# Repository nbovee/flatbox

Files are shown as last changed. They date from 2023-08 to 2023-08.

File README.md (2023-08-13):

# Flatbox: Low profile hitbox-layout fightstick

This repository contains 3D-printable models, PCB design files and code needed to make an arcade controller that looks like this:

Assembled Flatbox

There are five major versions of the Flatbox. As this is a fork, the three I do not have modifications planned for have been dropped, find them [here](https://github.com/jfedor2/flatbox). They all use Kailh low profile (choc v1) mechanical keyboard switches. The table below lists their main features. See the README for each version for details on how to make them.

version | [rev4](rev4b-pcb) | [rev5B](rev5b-pcb)
------- | --------------------- | ---------------------
case dimensions | 218x130x10mm | 218x126x10mm
compatibility (using provided firmware) | PC, PS3 | PC, PS3
add-on board | - | [RP2040-Zero](https://www.waveshare.com/rp2040-zero.htm)
onboard chip | RP2040 | - 
port | USB-C | USB-C
SMT assembly required | yes | no
firmware | [RP2040](firmware-rp2040) | [RP2040](firmware-rp2040)

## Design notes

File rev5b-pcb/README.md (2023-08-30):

# Flatbox rev5B

This is rev5B of the Flatbox. In this version an [RP2040-Zero](https://www.waveshare.com/rp2040-zero.htm) board is soldered onto the main PCB.
In this version L3 & R3 have been relocated to allow for usage during play (bindable macro's like MK+HK, burst, taunt, etc). 

To make one you will need:

* [3D printed case parts](../case-manufacturing-files) - Select a top and bottom. Two colors tops are available if you have a capable printer.
* [the Flatbox 5B PCB](manufacturing-files)

* [RP2040-Zero](https://www.waveshare.com/rp2040-zero.htm)

* 12-14x Kailh low profile (choc v1) switches of your choice
* (optionally) 12x Kailh low profile hotswap sockets
* [3D printed buttoncaps](../manufacturing-files/3d-printed-buttoncaps)
* 4-6x 6x6x5mm tact switches

* 7x M3x6 flat head screws
* some kind of rubber feet or non-slip padding for the bottom
* a soldering iron

I printed the case at 0.20mm layer height. The top part should be printed upside-down, the bottom part should be printed as-is. They don't require supports.

The PCB can be ordered from a number of online services using the included [Gerber files](manufacturing-files), I used [JLCPCB](https://jlcpcb.com/) (leave all the settings at default, you can choose the PCB color). PCB thickness should be 1.6mm.

The switches can be soldered in directly to the PCB or you can use hotswap sockets. If you want to use hotswap sockets, you will have to print the appropriate bottom part of the case (it's 1mm thicker).

Solder the jumpers for L3 & R3 at the locations they will be used (jumpers are located on the rear of the board).

For the firmware you probably want to use [GP2040-CE](https://gp2040-ce.info/). Go to the [GP2040-CE downloads page](https://gp2040-ce.info/#/download) and get the UF2 file for Flatbox rev5. Do not get the file for the Waveshare RP2040-Zero, even though your stick uses it (it has a different pinout).

To flash the firmware, connect the board to a computer with a USB cable, then press the RESET button while holding the BOOT button on the RP2040-Zero. A drive named "RPI-RP2" should appear. Copy the UF2 file you downloaded to that drive. That's it.

(Of course you can also use any other RP2040-compatible firmware if you want.)

To flash the firmware, connect the board to a computer with a USB cable, then press the RESET button while holding the BOOT button on the RP2040-Zero. A drive named "RPI-RP2" should appear. Copy the [flatbox-rev5.uf2](firmware/flatbox-rev5.uf2) file to that drive. That's it.

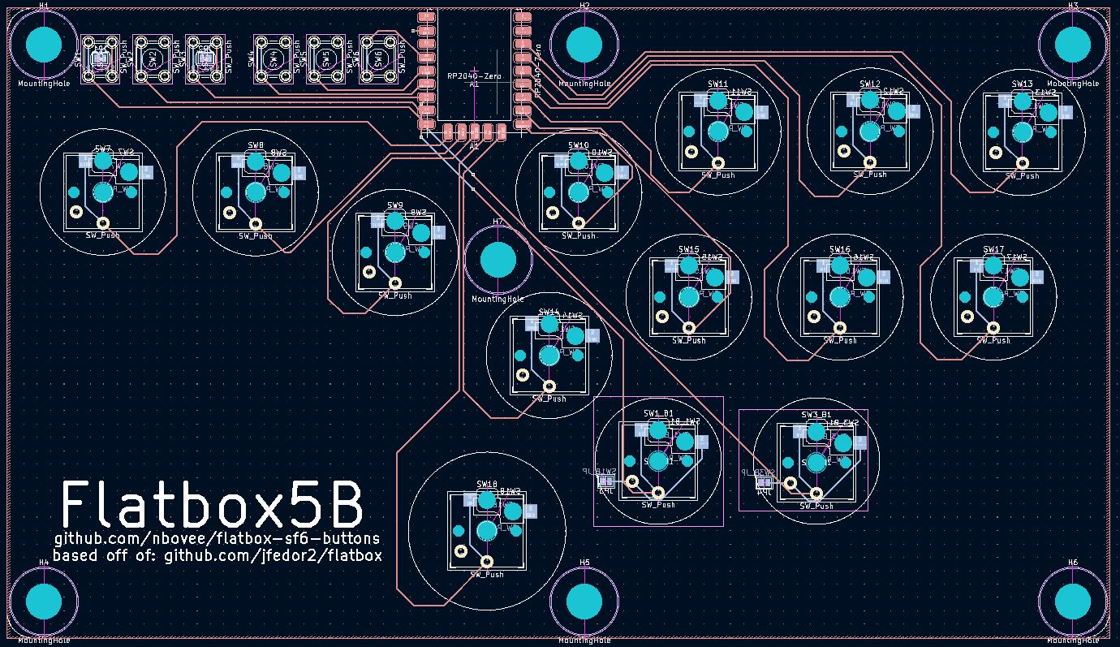
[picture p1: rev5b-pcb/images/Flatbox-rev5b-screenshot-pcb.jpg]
Flatbox rev5B KiCAD PCB


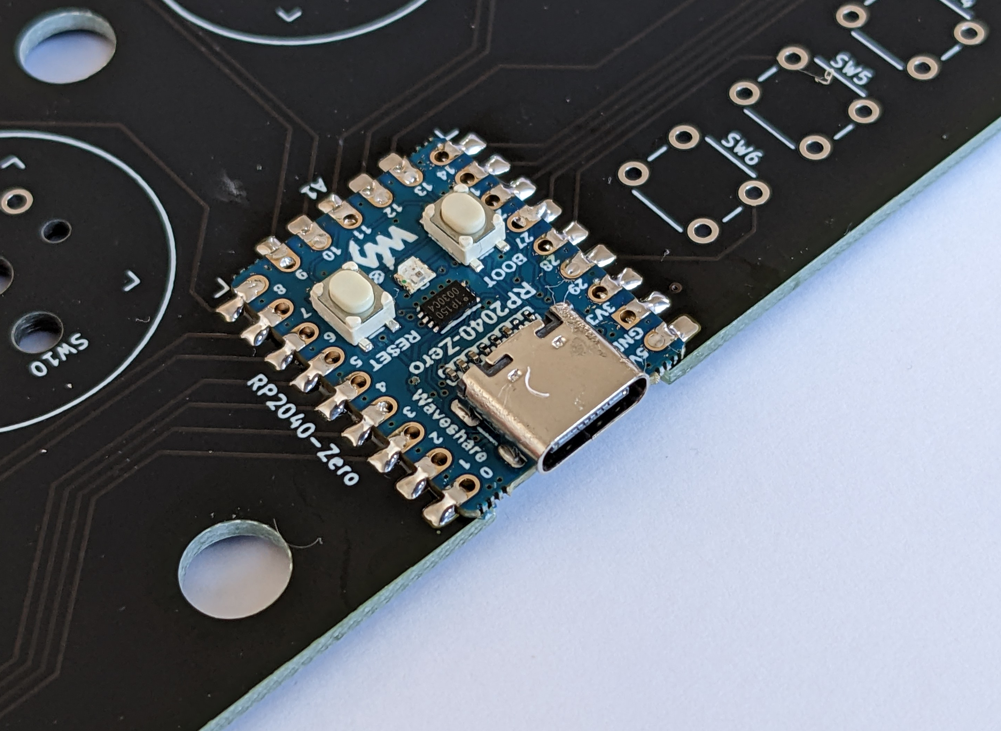
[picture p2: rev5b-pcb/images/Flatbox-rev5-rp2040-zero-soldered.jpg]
RP2040-Zero soldered on top of the PCB


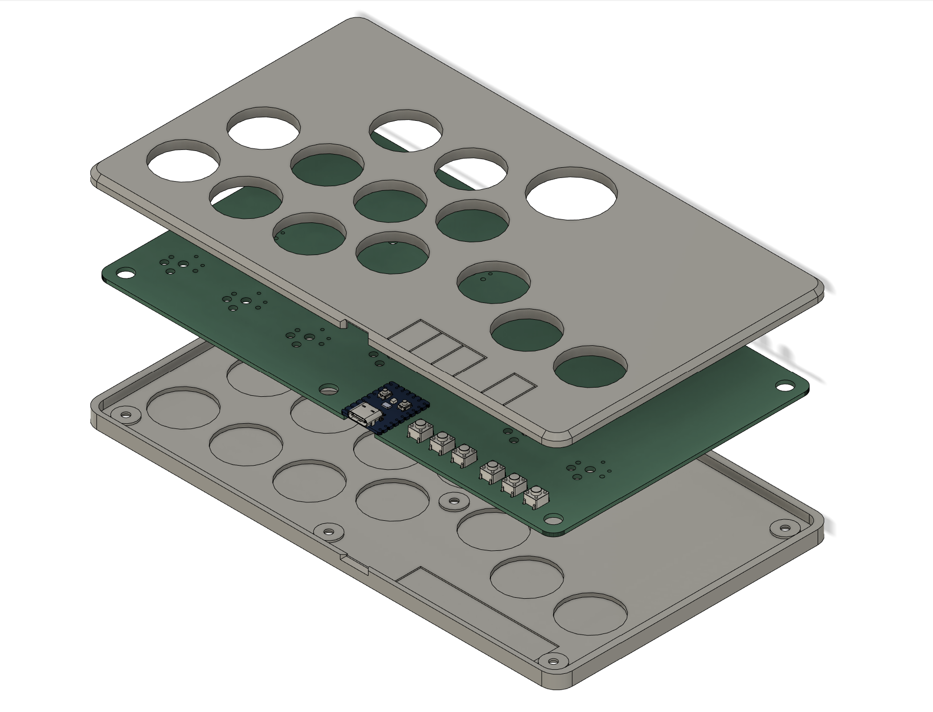
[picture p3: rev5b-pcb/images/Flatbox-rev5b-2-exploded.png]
Flatbox rev5B exploded view of the 3D printed case (option 2 selected)


PCB design licensed under [CC BY-SA 4.0](https://creativecommons.org/licenses/by-sa/4.0/).

PCB design uses the following:

* [keyswitches.pretty](https://github.com/daprice/keyswitches.pretty) by [daprice](https://github.com/daprice) ([CC BY-SA 4.0](https://creativecommons.org/licenses/by-sa/4.0/))
* RP2040-Zero STEP file downloaded from [Waveshare wiki](https://www.waveshare.com/wiki/RP2040-Zero)

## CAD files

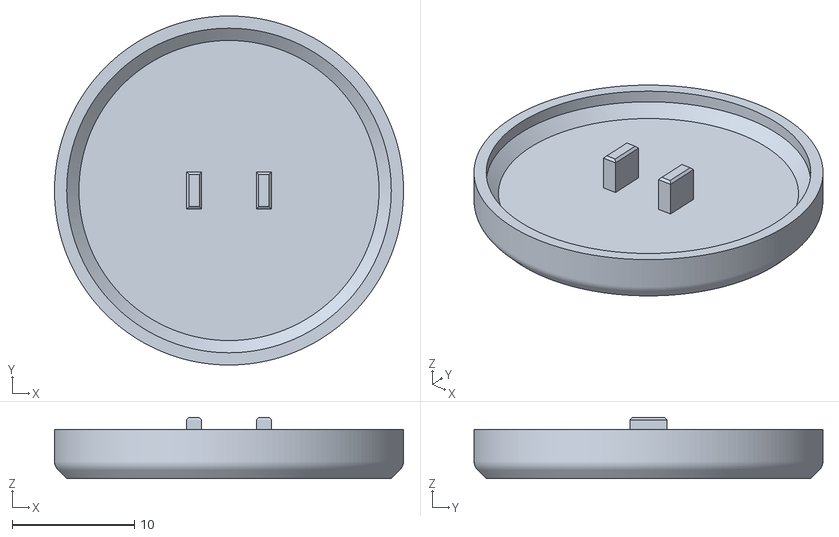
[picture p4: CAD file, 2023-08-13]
case-manufacturing-files/3d-printed-buttoncaps/ButtoncapBig.stl
28.5 x 28.5 x 5.00

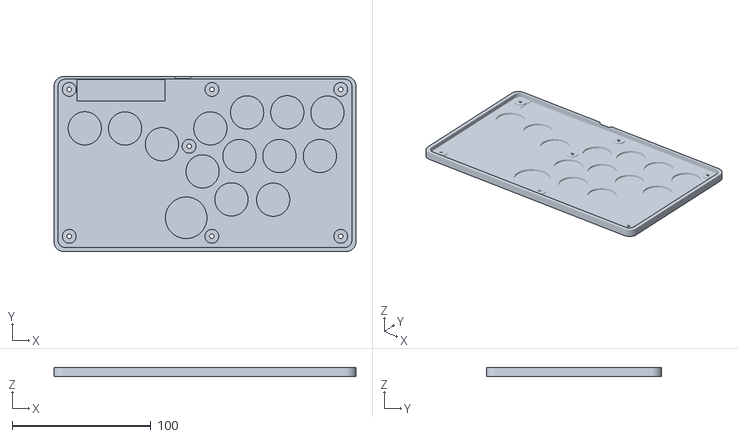
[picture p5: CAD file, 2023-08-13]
case-manufacturing-files/Flatbox-case-Bottom-hotswap.stl
218.0 x 126.4 x 6.20

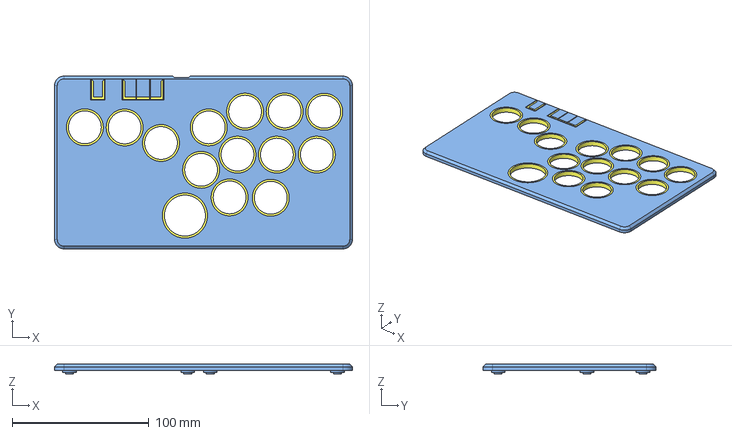
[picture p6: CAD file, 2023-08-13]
mcad_src/Flatbox-rev5B-case-14button-2color.step
218.0 x 126.4 x 7.20 mm

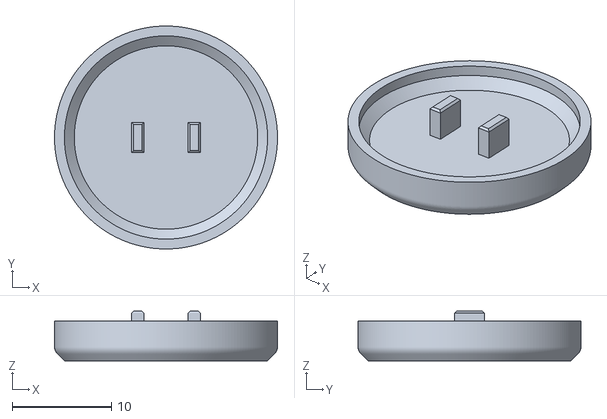
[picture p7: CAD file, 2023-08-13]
case-manufacturing-files/3d-printed-buttoncaps/Buttoncap.stl
22.5 x 22.5 x 5.00

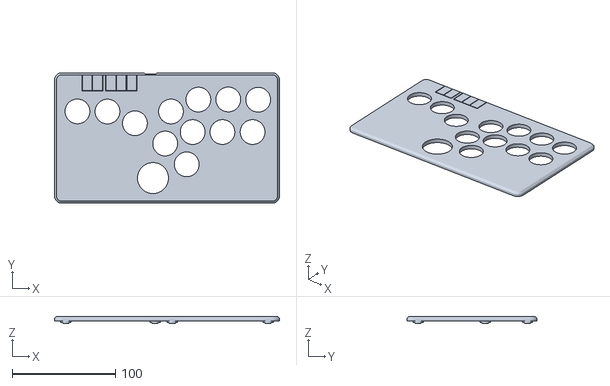
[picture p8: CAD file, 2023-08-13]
case-manufacturing-files/Flatbox-case-Top-13button-1color.stl
218.0 x 126.4 x 7.20

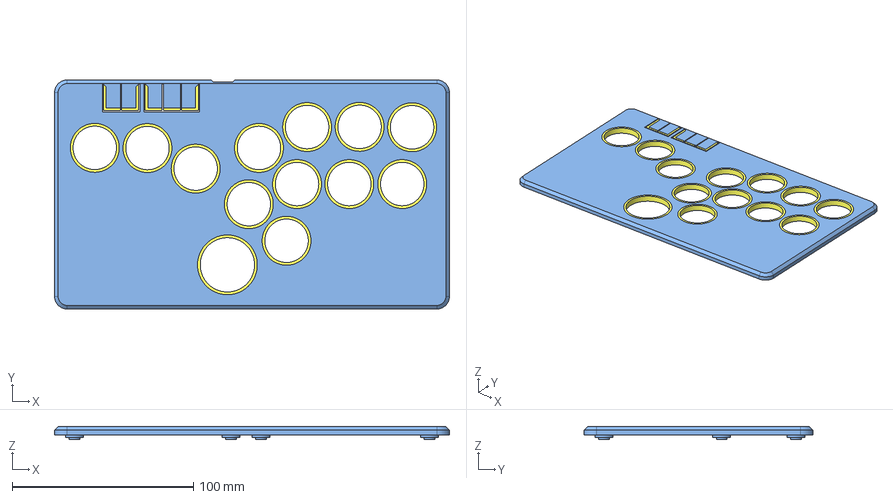
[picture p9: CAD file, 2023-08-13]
mcad_src/Flatbox-rev5B-case-13button-2color.step
218.0 x 126.4 x 7.20 mm

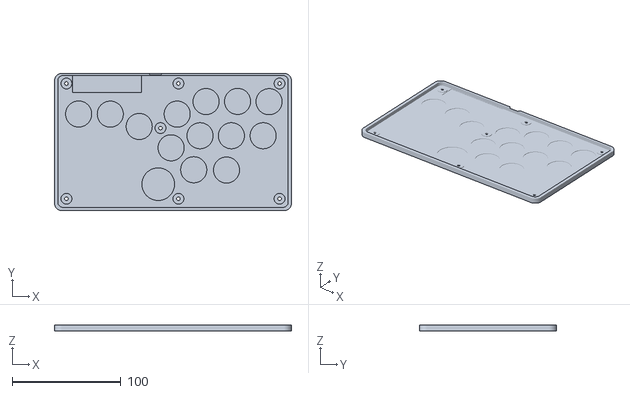
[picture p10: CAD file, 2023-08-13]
case-manufacturing-files/Flatbox-case-Bottom.stl
218.0 x 126.4 x 5.20

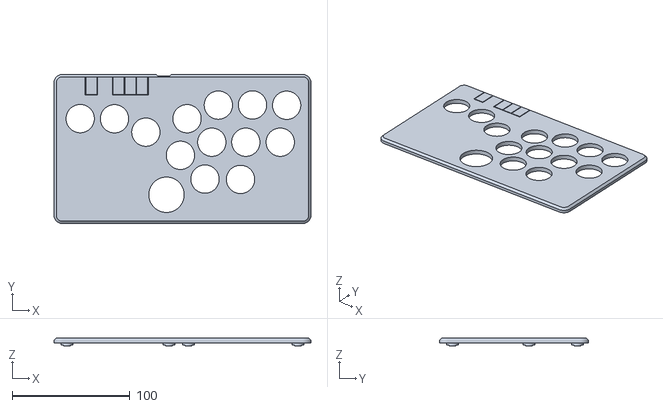
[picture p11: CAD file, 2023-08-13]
case-manufacturing-files/Flatbox-case-Top-14button-1color.stl
218.0 x 126.4 x 7.20

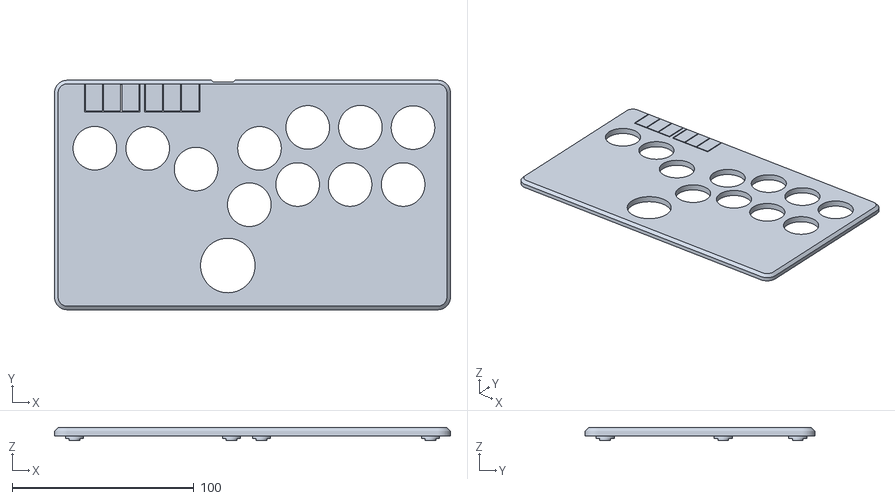
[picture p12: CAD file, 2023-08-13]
case-manufacturing-files/Flatbox-case-Top-12button-1color.stl
218.0 x 126.4 x 7.20

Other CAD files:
mcad_src/Flatbox-rev5B-case-bottom-hotswap.step

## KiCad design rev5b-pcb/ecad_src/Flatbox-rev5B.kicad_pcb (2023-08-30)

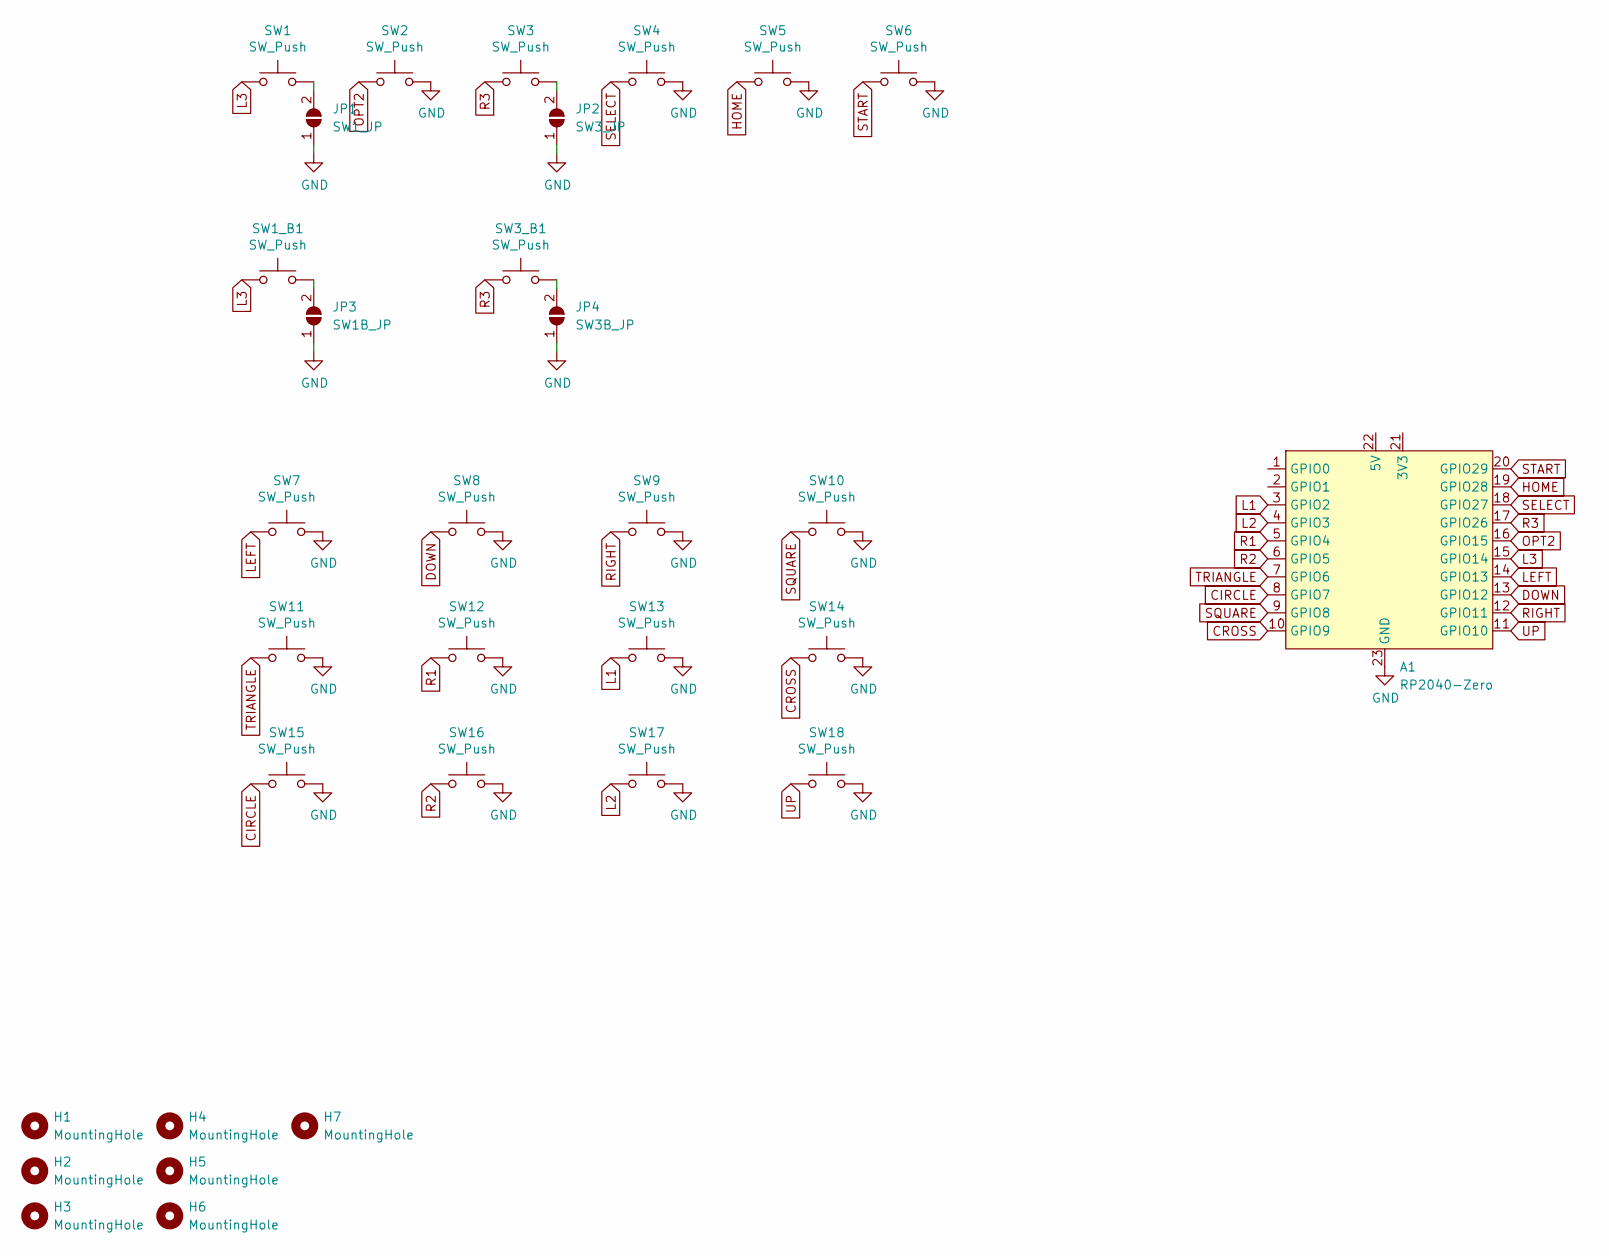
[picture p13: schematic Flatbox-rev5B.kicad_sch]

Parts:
A1: RP2040-Zero
H1, H2, H3, H4, H5, H6, H7: MountingHole; MountingHole_6.4mm_M6
JP1: SW1_JP; SolderJumper-2_P1.3mm_Open_Pad1.0x1.5mm
JP2: SW3_JP; SolderJumper-2_P1.3mm_Open_Pad1.0x1.5mm
JP3: SW1B_JP; SolderJumper-2_P1.3mm_Open_Pad1.0x1.5mm
JP4: SW3B_JP; SolderJumper-2_P1.3mm_Open_Pad1.0x1.5mm
SW1, SW2, SW3, SW4, SW5, SW6: SW_Push; SW_PUSH_6mm_H5mm
SW1_B1, SW3_B1, SW7, SW8, SW9, SW10, SW11, SW12, SW13, SW14, SW15, SW16, SW17, SW18: SW_Push; Kailh_socket_PG1350_optional

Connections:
CIRCLE: A1.8 (GPIO7), SW15.1
CROSS: A1.10 (GPIO9), SW14.1
DOWN: A1.13 (GPIO12), SW8.1
GND: A1.23 (GND), JP1.1 (A), JP2.1 (A), JP3.1 (A), JP4.1 (A), SW2.2, SW4.2, SW5.2, SW6.2, SW7.2, SW8.2, SW9.2, SW10.2, SW11.2, SW12.2, SW13.2, SW14.2, SW15.2, SW16.2, SW17.2, SW18.2
HOME: A1.19 (GPIO28), SW5.1
L1: A1.3 (GPIO2), SW13.1
L2: A1.4 (GPIO3), SW17.1
L3: A1.15 (GPIO14), SW1.1, SW1_B1.1
LEFT: A1.14 (GPIO13), SW7.1
unnamed: JP1.2 (B), SW1.2
unnamed: JP2.2 (B), SW3.2
unnamed: JP3.2 (B), SW1_B1.2
unnamed: JP4.2 (B), SW3_B1.2
OPT2: A1.16 (GPIO15), SW2.1
R1: A1.5 (GPIO4), SW12.1
R2: A1.6 (GPIO5), SW16.1
R3: A1.17 (GPIO26), SW3.1, SW3_B1.1
RIGHT: A1.12 (GPIO11), SW9.1
SELECT: A1.18 (GPIO27), SW4.1
SQUARE: A1.9 (GPIO8), SW10.1
START: A1.20 (GPIO29), SW6.1
TRIANGLE: A1.7 (GPIO6), SW11.1
UP: A1.11 (GPIO10), SW18.1

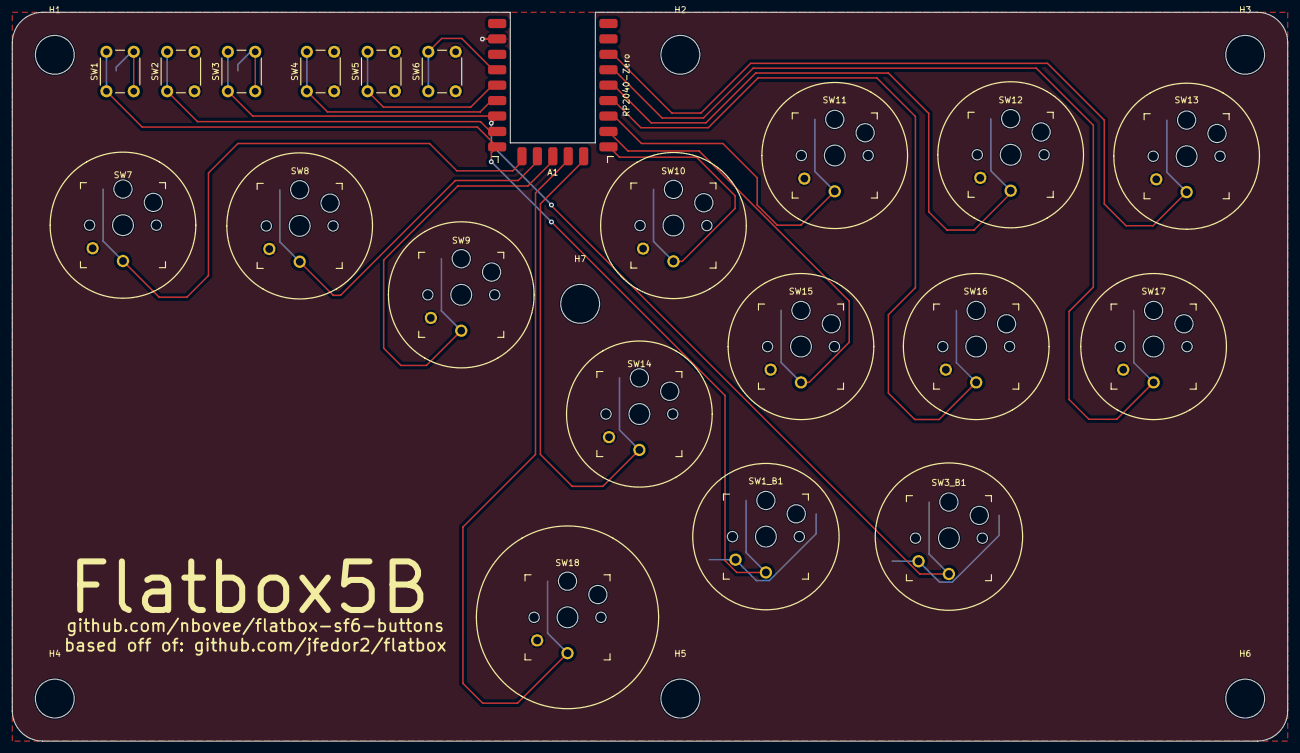
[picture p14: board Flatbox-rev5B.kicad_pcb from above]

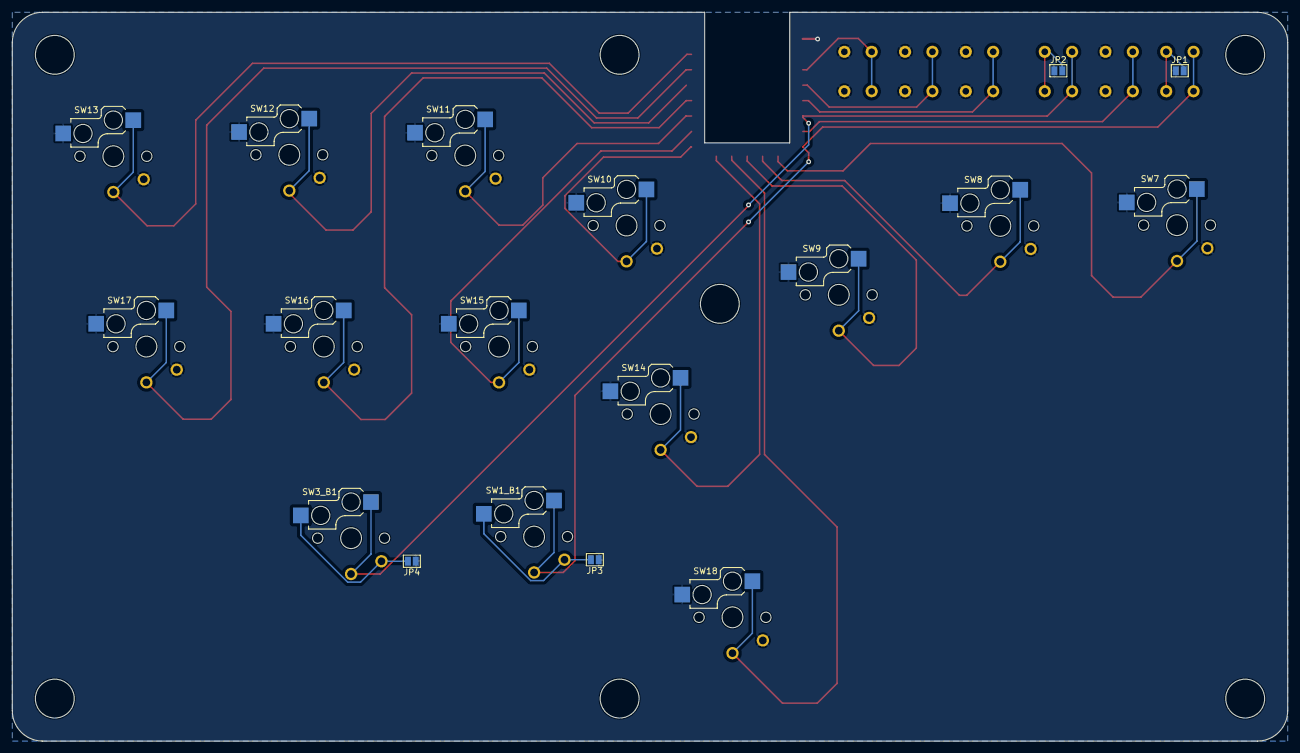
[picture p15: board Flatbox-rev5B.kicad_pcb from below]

Board: 2 copper layers, 210.0 x 120.0 mm, 32 parts (4 on the bottom side), 23 nets.

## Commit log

2023-08-13 add color regions to new case tops
    [Flatbox-rev5B-case1-colors2.step, Flatbox-rev5B-case2-colors2.step]
2023-08-13 drop versions I dont want to support
    [Flatbox-rev1.1-Bottom-hotswap.stl, Flatbox-rev1.1-Bottom.stl, Flatbox-rev1.1-Top.stl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]
2023-08-13 drop rev5
    [Flatbox-rev5-Bottom-hotswap.stl, Flatbox-rev5-Bottom.stl, Flatbox-rev5-Top.stl]
2023-08-13 expose kicad files for versioning
    [Flatbox-rev5B-B_Cu.gbl, Flatbox-rev5B-B_Mask.gbs, Flatbox-rev5B-B_Paste.gbp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]
2023-08-13 note about two color case
2023-08-13 drop license from root, it applies to PCB only
2023-08-13 add manufacturing files
    [Flatbox-case-Top-13button-2color.stl, Flatbox-case-Top-14button-2color.stl, Flatbox-rev5B-case-13button-2color.step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]
2023-08-30 5B update
    [Flatbox-rev5B-B_Cu.gbl, Flatbox-rev5B-B_Mask.gbs, Flatbox-rev5B-B_Paste.gbp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]
2023-08-30 drop 4B until updated
    [Flatbox-rev4-BOM.csv, Flatbox-rev4-Bottom-hotswap.stl, Flatbox-rev4-Bottom.stl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]
2023-08-30 drop 2 color case until I can push the correct stl
    [Flatbox-case-Top-13button-2color.stl, Flatbox-case-Top-14button-2color.stl]
